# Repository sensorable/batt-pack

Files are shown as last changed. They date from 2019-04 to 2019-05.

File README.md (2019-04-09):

# 2P3S Battery Pack
### Designed for use with Sensorable Open Source Cameras

## Specification

* Charging voltage: 14v ... 36v
* Output voltage: 9.3v ... 12.6v
* Batteries: Li-Ion 18650 x3 or x6
* Operational temp: 0C ... 40C
* Enclosure: RP1170
* Water ingress: IP65 with a breathable valve
* Size: 165mm x 86mm x 40mm

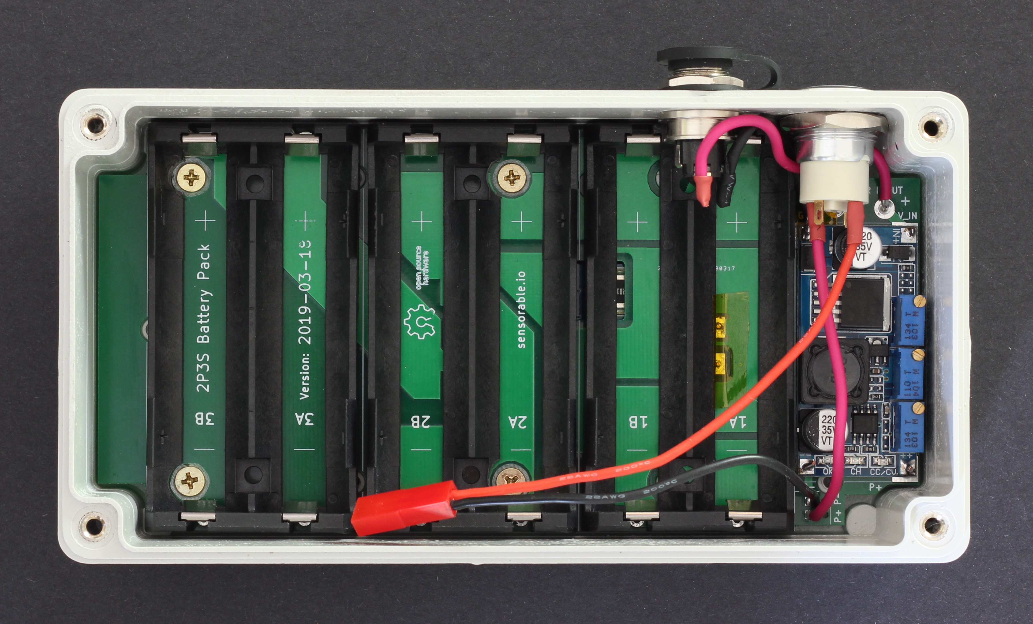
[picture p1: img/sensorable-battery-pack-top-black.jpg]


## Overview

This battery pack combines several COTS components to allow short production runs with manual assembly. All components are "though-hole" and the whole unit can be ordered and put together by any sufficiently skilled individual. It is not suitable for an automated PCBA process or large production runs.

Charging sources:

* a laptop charger with a barrel connector
* an intermittent power source like street lights, via a transformer
* a solar panel, but the efficiency can be low due to lack of MPPT

**Restarting the pack**

1. Insert the batteries
2. Connect a charger for a brief moment

The BMS requires external voltage close to the pack output to be connected from the outside for it to start working. You need to connect a charger or any similar source of voltage if you removed and re-inserted the batteries.

## Batteries

**Use only high quality Li-Ion 18650 batteries from a trusted manufacturer, e.g. NCR18650B and NCR18650GA from Panasonic.**

The battery holders are connected as 2P-3S, that is, the 2 batteries in the same holder are connected in parallel and the holders are connected in series. This way you can use either 3 or 6 battery cells.

* 3-cell configuration: place one battery into each holder numbered 1,2,3
* 6-cell configuration: fill in all available slots

The charger unit has to be adjusted to the battery type and the size of the pack. Use the 2 blue potentiometers to set the voltage to 4.2v and limit the current to less than 1A, if using NCR18650GA. Check your battery datasheet if using a different type.

The batteries are protected with a commercial BMS module with load balancing. Use only new batteries from the same batch and at exactly the same voltage. The load balancing feature will maintain them in that state, but it will not balance out mismatched batteries.

**BMS spec from the manufacturer datasheet:**
* Charging voltage: 12.6v
* Balance voltage per cell: 4.2v
* Balance current per cell: 42mA
* Max discharge current: 4.5A
* Overcharge protection: 4.35v +/-0.025v
* Overdischarge protection: 2.7v per cell

## Ordering and assembly

1. See the BOM file for the list of components and suppliers
2. We used JLCPCB for making the PCBs with a good result
3. Use cutting and drilling templates from the repo to modify the enclosure

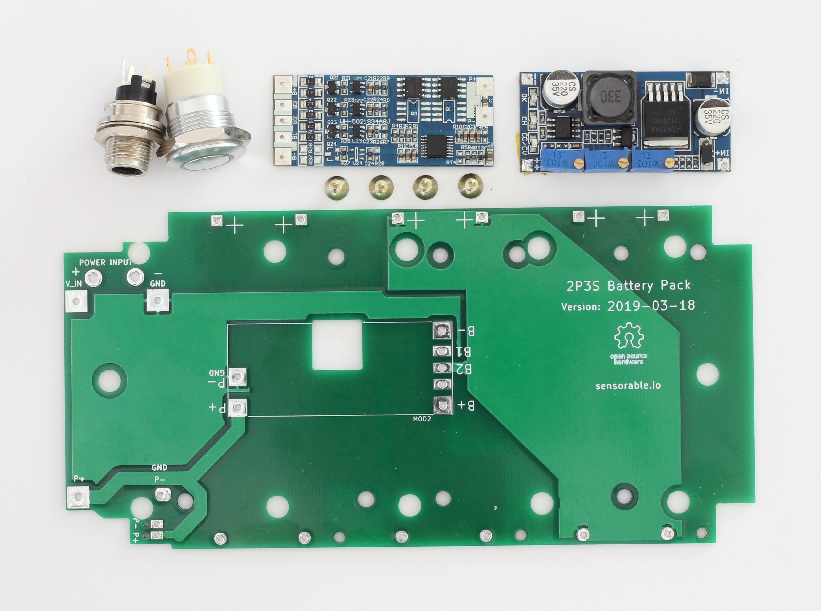
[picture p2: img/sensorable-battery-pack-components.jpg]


## Enclosure assembly instructions

* Trim the breathable valve by 4mm if placed on the back face under the board. Insert the valve from the inside of the case, tighten the nut back side out, cut off the white plastic flush to the nut.
* Counter-sink post to match the board counter-sinks 
* Mark holes for the switch and PWR IN.
* Check that the holes are marked correctly in relation to the countersunk holes and the vent.

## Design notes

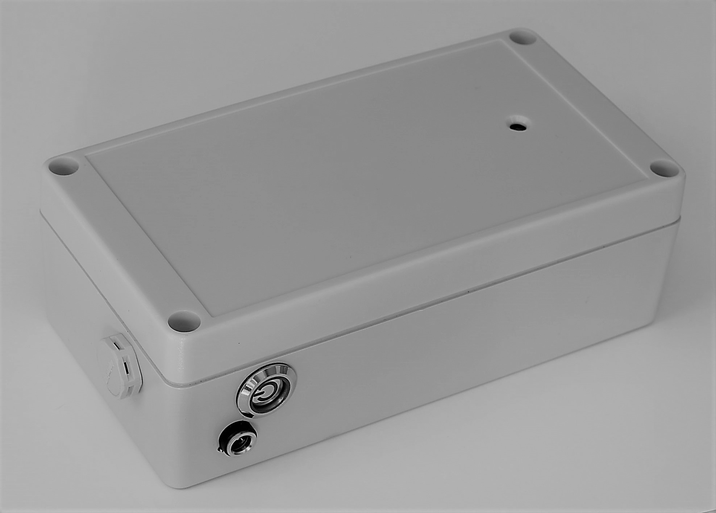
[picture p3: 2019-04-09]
img/full-enclosure-with-batt-pack.jpg

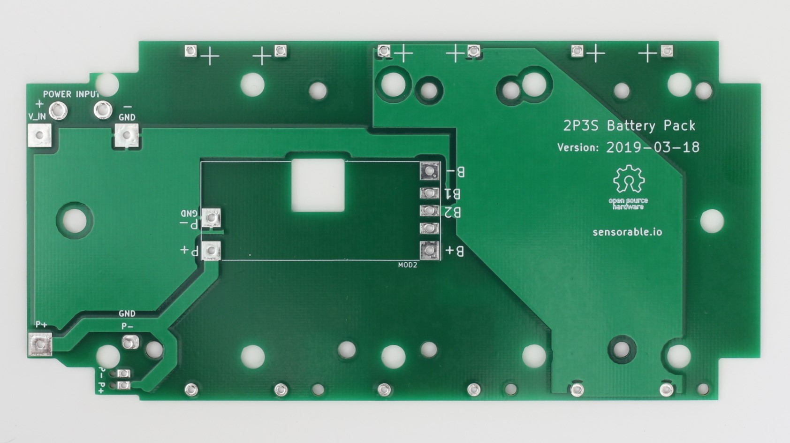
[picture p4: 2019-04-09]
img/batt-pack-pcb.jpg

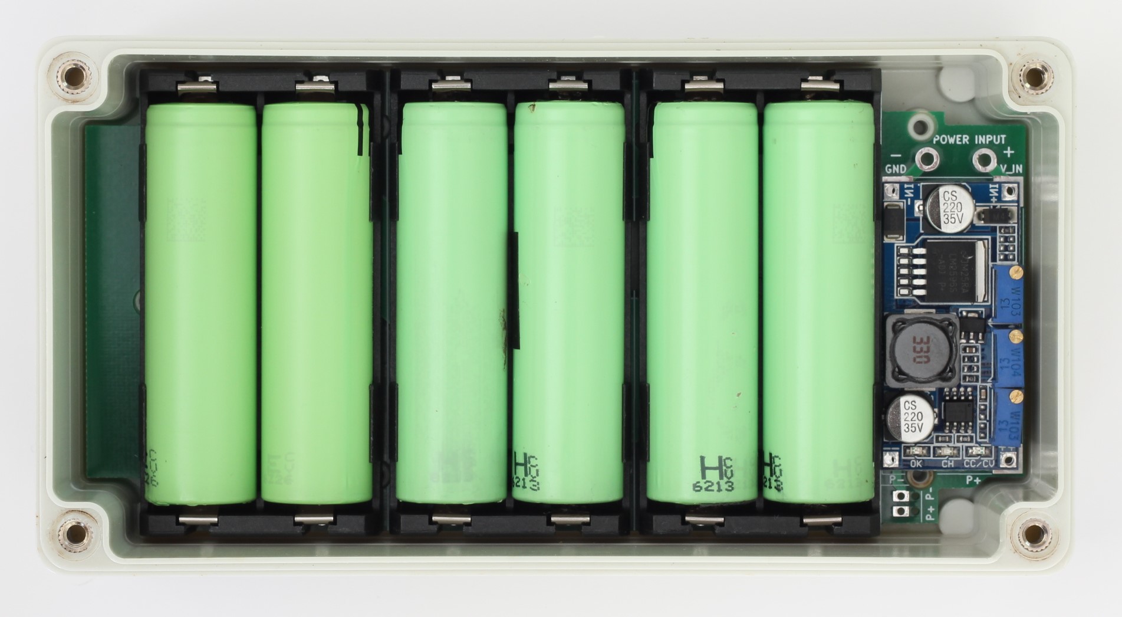
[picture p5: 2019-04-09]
img/batt-pack-w-batt2.jpg

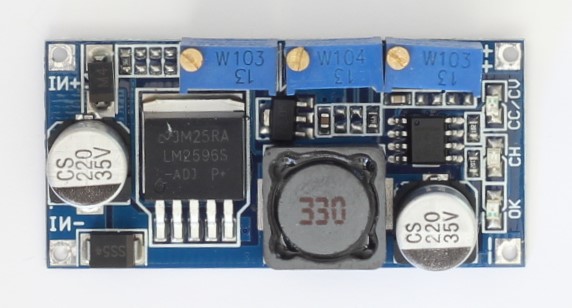
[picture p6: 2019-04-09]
img/cc-cv-3pots.jpg

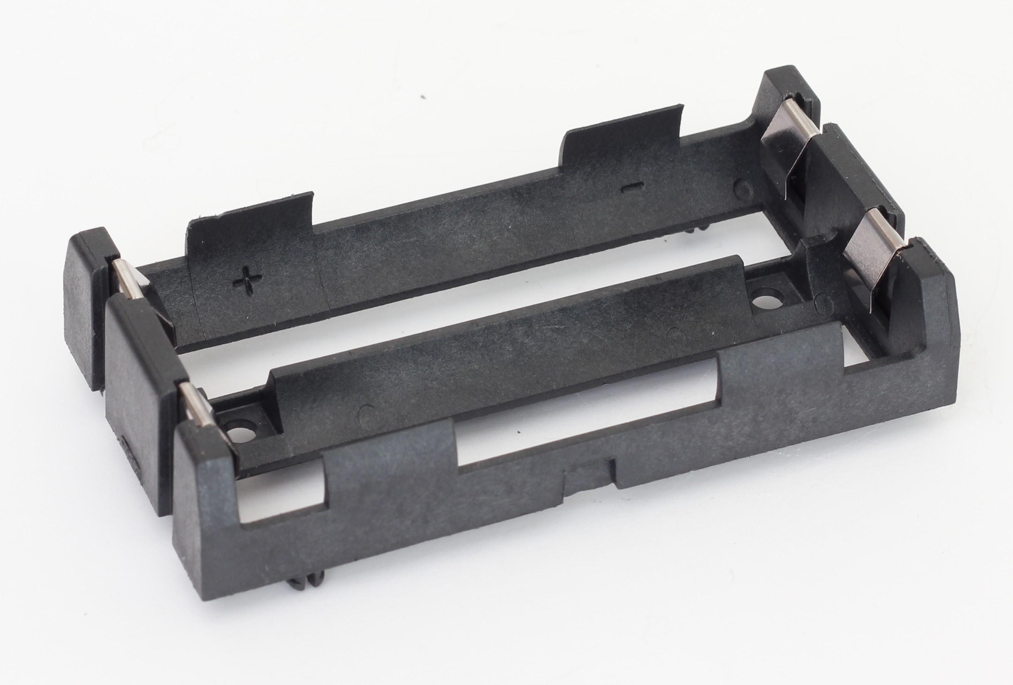
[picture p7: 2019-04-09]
img/keystone-18650-holder-1049-side-top.jpg

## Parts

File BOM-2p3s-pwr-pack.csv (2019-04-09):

Component | Supplier SKU | Manufacturer SKU | Qty per unit | Supplier link | Comments
PCB |  |  | 1 | https://jlcpcb.com/
BMS w/load balancing |  |  | 1 | https://www.aliexpress.com/item/3S-4A-11-1V-li-ion-BMS-PCM-battery-protection-board-bms-pcm-with-balancing-for/32377617462.html | Verify the pads match
CC/CV DC/DC converter |  |  | 1 | https://www.aliexpress.com/item/DC-DC-LM2596-HV-S-60V-3A-Buck-Constant-Current-Voltage-CC-CV-Step-Down-Module/32756197860.html | Must be exactly the same model to fit other components around it.
Thermal pad | 1168-2175-ND | TGX-150-150-1.5 | 0.02 | https://www.digikey.com/product-detail/en/t-global-technology/TGX-150-150-1.5/1168-2175-ND/7360875 | The sheet cuts into 50 pcs of 15mmx30mm. Place under CC/CV
IP65 latching button switch | EG5508-ND | PVA6LRE21231 | 1 | https://www.digikey.com/product-detail/en/PVA6LRE21231/EG5508-ND/7423421/?itemSeq=287488044 | Power On/Off
Barrel jack, 2.5/5.5 | SC1393-ND | PCL722AS | 1 | https://www.digikey.com/product-detail/en/PCL722AS/SC1393-ND/2238436/?itemSeq=287374077 | External charger connector
Rubber seal | SC1396-ND | JCAP | 1 | https://www.digikey.com/product-detail/en/switchcraft-inc/JCAP/SC1396-ND/2251492 | For the barrel jack
Battery holders for 18650 | 36-1049-ND | 1049 | 3 | https://www.digikey.com/product-detail/en/keystone-electronics/1049/36-1049-ND/2745670
JST RCY pre-crimped leads |  |  | 1 | https://www.trademe.co.nz/electronics-photography/other-electronics/electronic-components/other/listing-1980231570.htm | No major distributors stock pre-crimped ones. Source from a local hobby store.
4G x 8 plastite screws | SPK45-3-8-A2 | SPK45-3-8-A2 | 5 | https://www.accu.co.uk/en/plastite-45-pozi-countersunk-screws/24197-SPK45-3-8-A2 | These are supplied with the enclosure, but we may need CSK
Jumper wire |  |  | 1 |  | Soldering the pushbutton, jack, etc.
NCR18650xx batteries |  |  | 6 |  | Adjust the current on CC/CV to match the battery capacity

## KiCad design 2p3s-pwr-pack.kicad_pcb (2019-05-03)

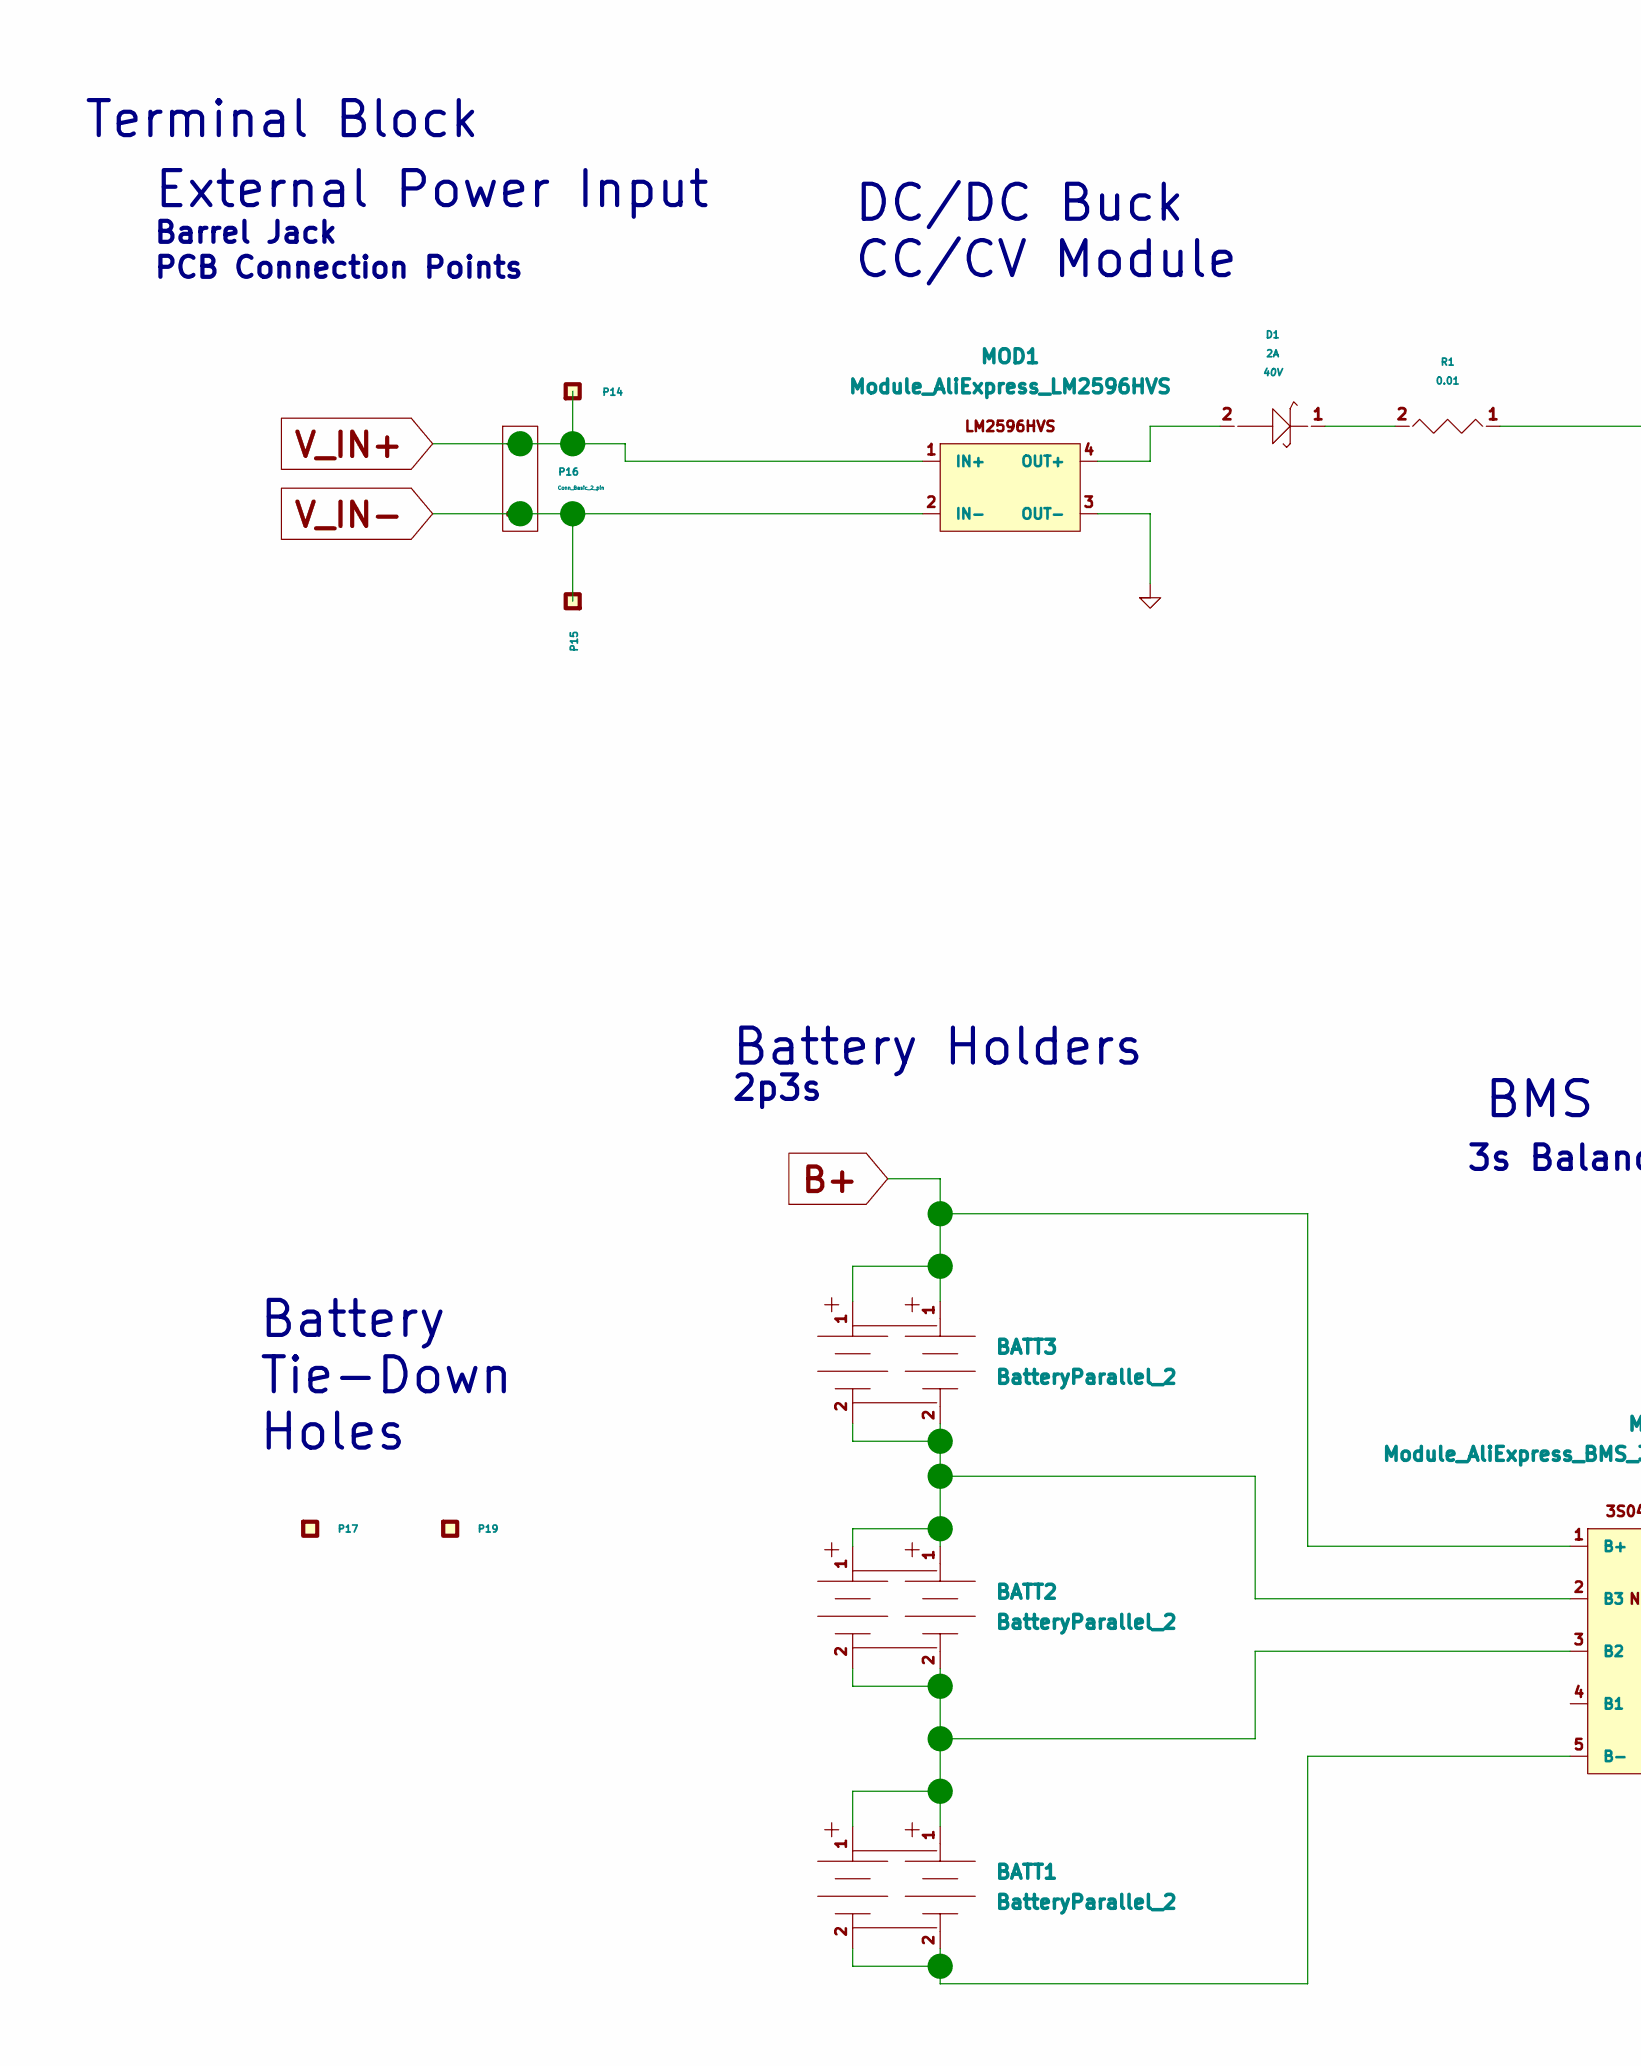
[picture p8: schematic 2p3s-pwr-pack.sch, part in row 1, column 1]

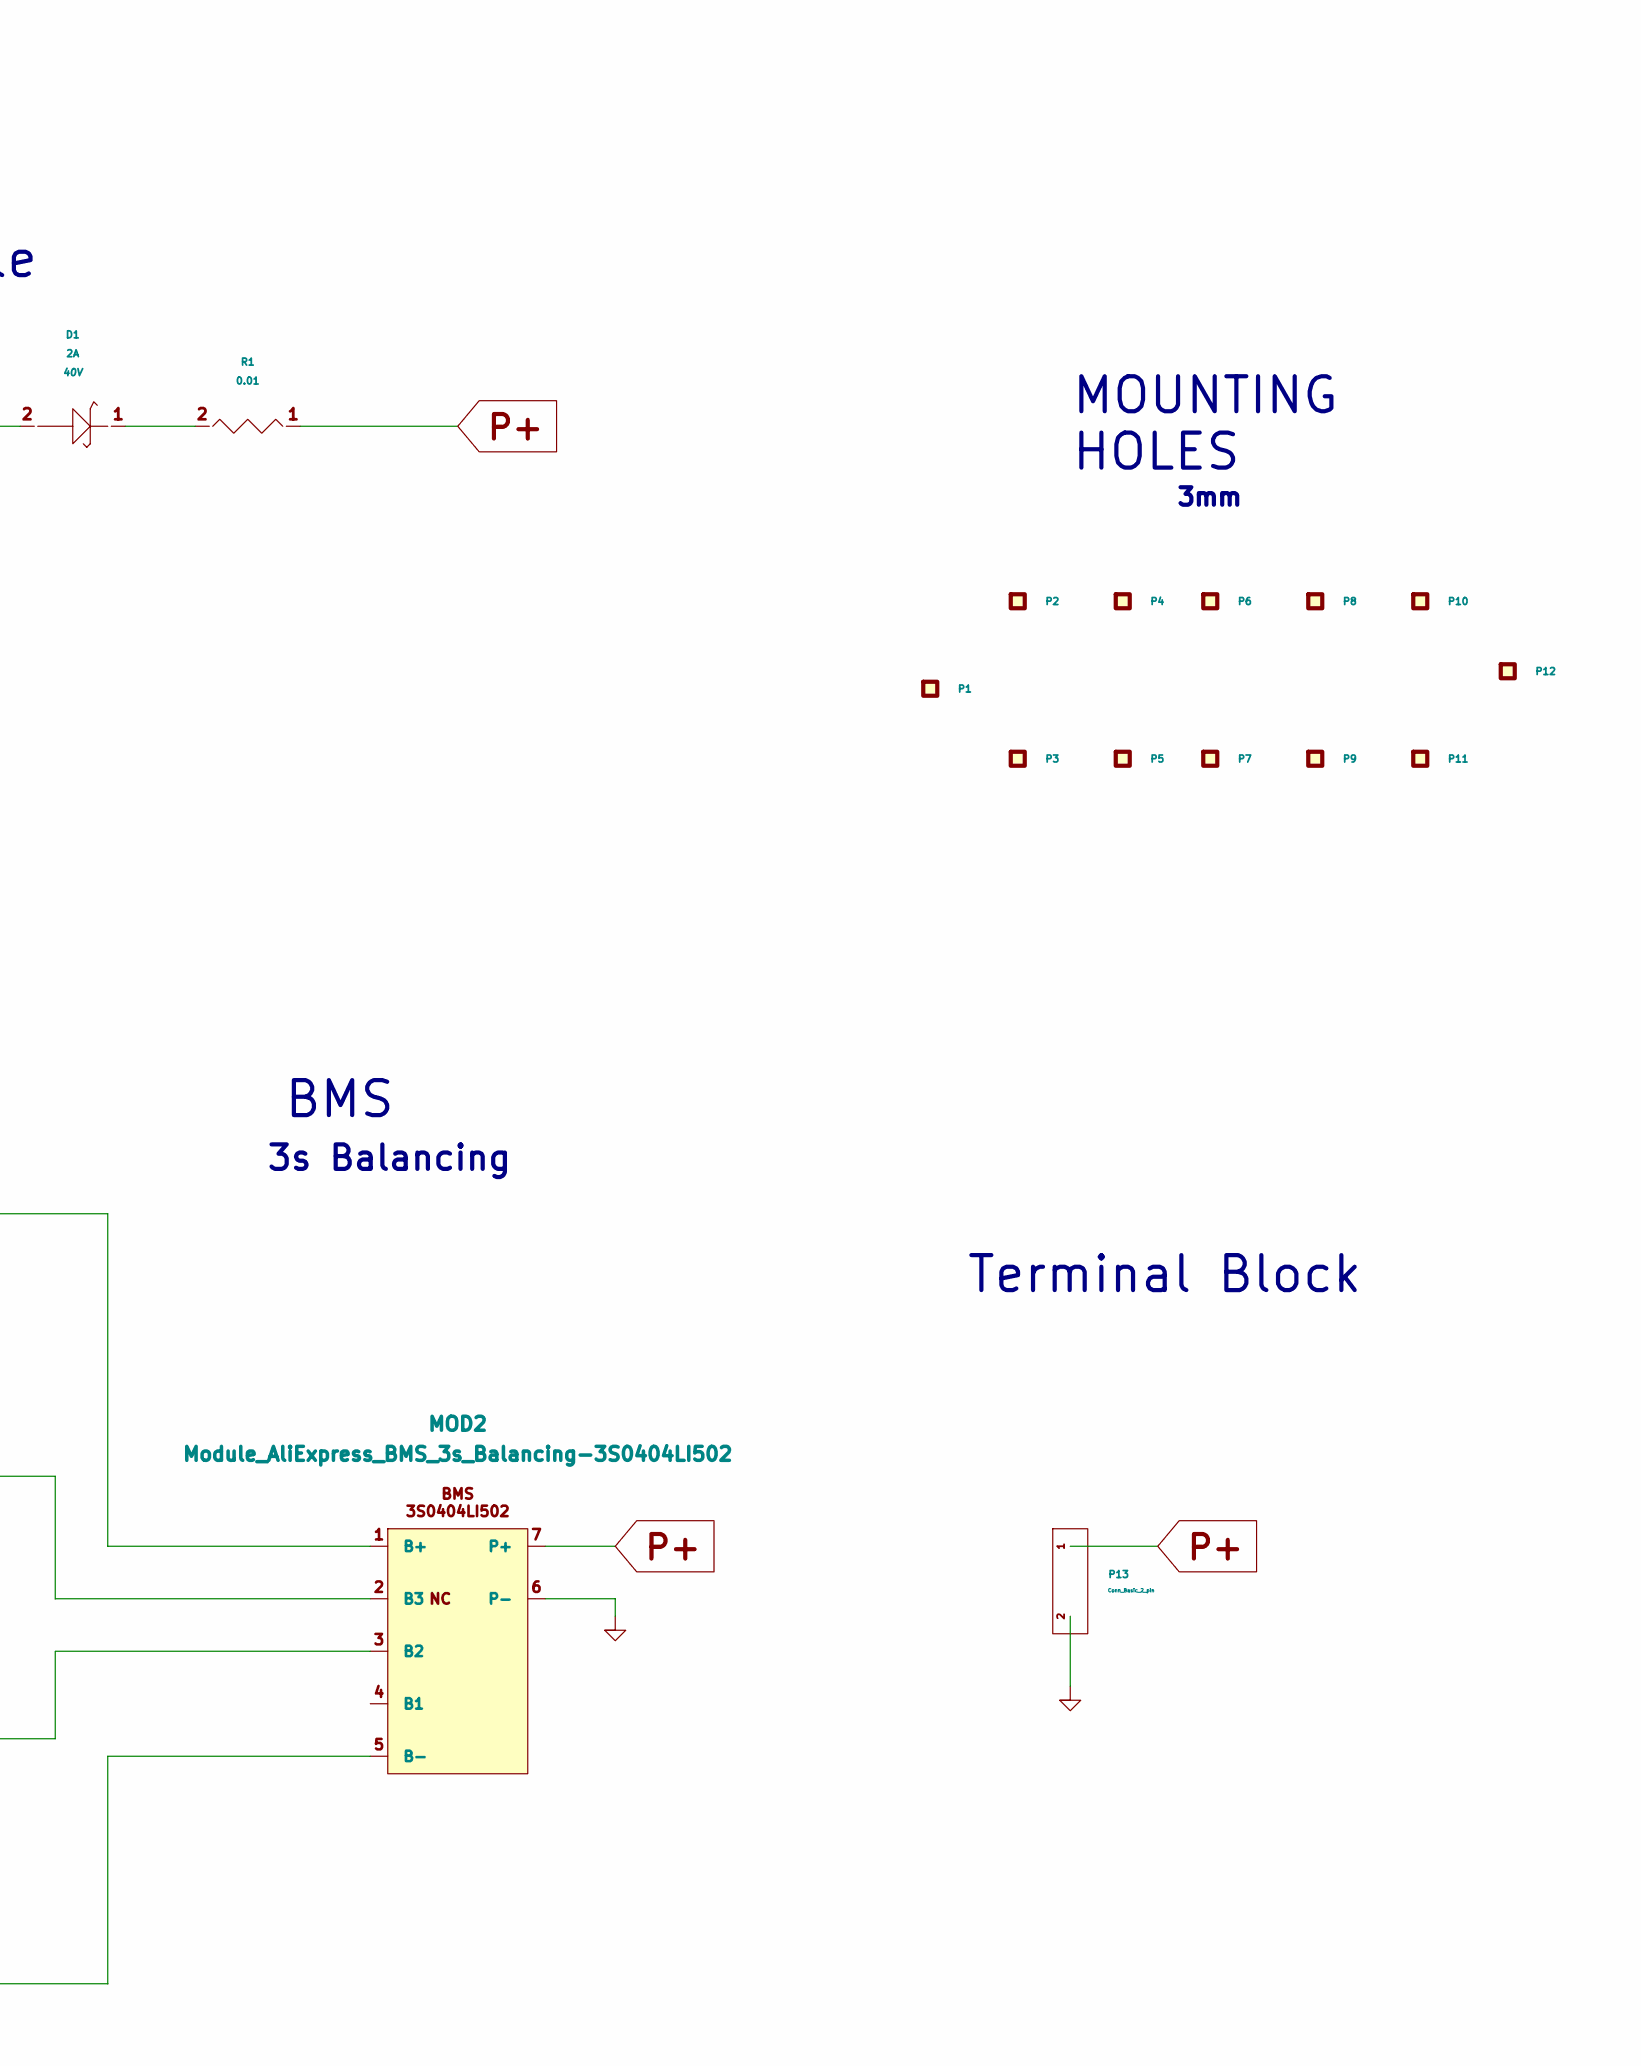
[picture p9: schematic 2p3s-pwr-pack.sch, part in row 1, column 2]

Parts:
BATT1, BATT2, BATT3: BatteryParallel_2; KEYSONE_1049_2x_18650_HOLDER; Manufacturer1PartNumber 1049
D1: 2A; SMA; Voltage 40V; Manufacturer1PartNumber B240AE-13
MOD1: Module_AliExpress_LM2596HVS
MOD2: Module_AliExpress_BMS_3s_Balancing-3S0404LI502; Module_BMS_Balancing_3s_AliExpress_BMS-3S0404LI502; Manufacturer1PartNumber MFG1PN
P1, P2, P3, P4, P5, P6, P7, P8, P9, P10, P11, P12: PAD; NPTH_5mm; Manufacturer1PartNumber MFG1PN
P13, P16: Conn_Basic_2_pin; TERM_BLK_2_SIDE_2.54MM; Manufacturer1PartNumber 1725656
P14, P15: PAD; HOLE_4mmx2.2mm; Manufacturer1PartNumber MFG1PN
P17, P19: PAD; NPTH_3mm; Manufacturer1PartNumber MFG1PN
R1: 0.01; 1206_Medium_Pads; Tolerance 5%; Manufacturer1PartNumber ERJ-8CWJR010V

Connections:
B+: BATT3.1, MOD2.1 (B+)
GND1: MOD1.3 (OUT-), MOD2.6 (P-), P13.2
unnamed: BATT1.1, BATT2.2, MOD2.3 (B2)
unnamed: BATT1.2, MOD2.5 (B-)
unnamed: BATT2.1, BATT3.2, MOD2.2 (B3)
unnamed: D1.1, R1.2
unnamed: D1.2, MOD1.4 (OUT+)
P+: MOD2.7 (P+), P13.1, R1.1
V_IN+: MOD1.1 (IN+), P14.1, P16.1
V_IN-: MOD1.2 (IN-), P15.1, P16.2

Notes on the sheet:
MOUNTING HOLES
3mm
Terminal Block
External Power Input
Barrel Jack
PCB Connection Points
Battery Holders
3s Balancing
BMS
2p3s
DC/DC Buck CC/CV Module
Battery Tie-Down Holes

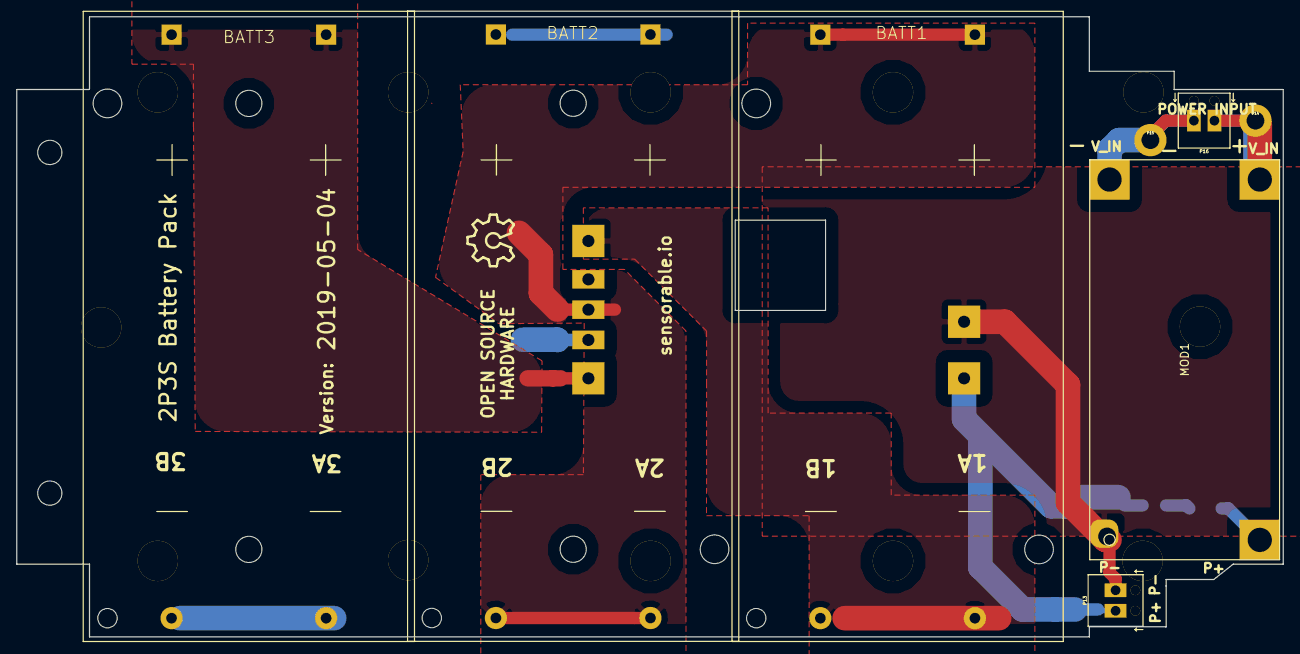
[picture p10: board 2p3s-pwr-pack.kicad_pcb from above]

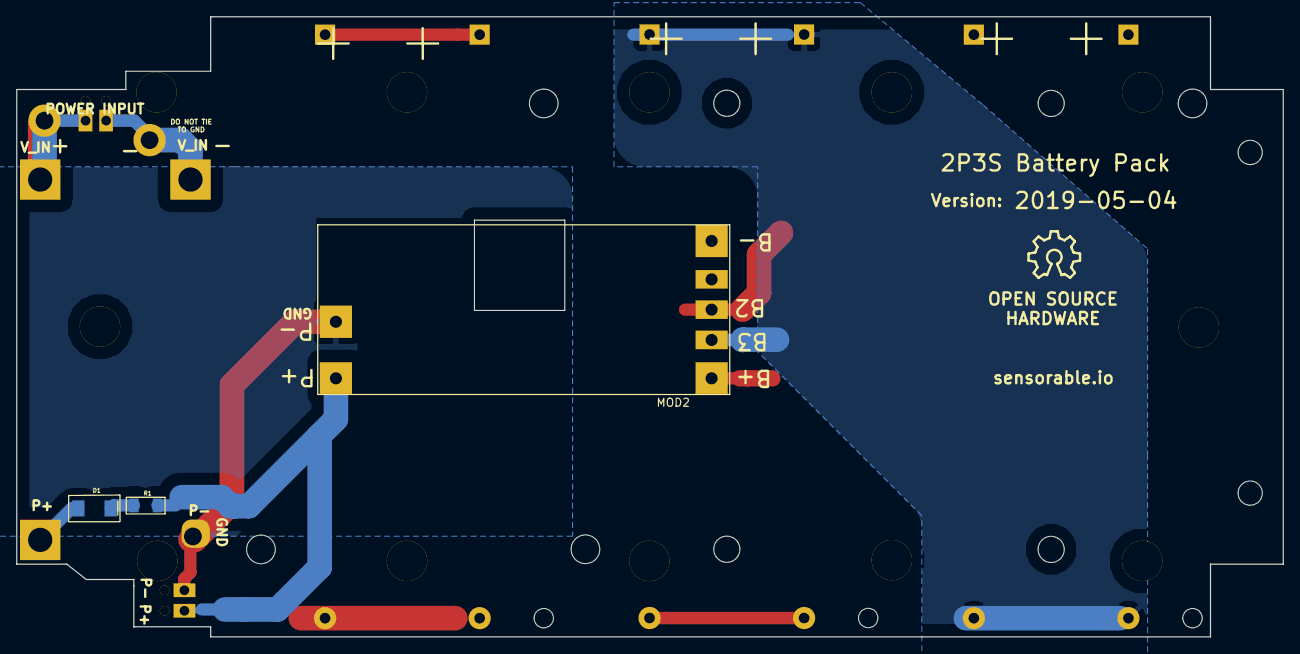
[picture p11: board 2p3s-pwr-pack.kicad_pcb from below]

Board: 2 copper layers, 156.8 x 76.8 mm, 25 parts (3 on the bottom side), 10 nets.

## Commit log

2019-03-16 A prorotype for review
    [2p3s-pwr-pack.kicad_pcb, 2p3s-pwr-pack.sch]
2019-03-16 Git LFS fix - added .stl
2019-03-17 2019-03018 ready for ordering.
    [2p3s-pwr-pack-B.Cu.gbl, 2p3s-pwr-pack-B.Fab.gbr, 2p3s-pwr-pack-B.Mask.gbs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]
2019-03-17 Added BOM
    [2p3s-pwr-pack-bom.csv]
2019-03-24 BOM and Readme updates.
    [2p3s-pwr-pack-bom.csv]
2019-04-09 Missin KiCad files.
2019-04-09 Renamed BOM
    [BOM-2p3s-pwr-pack.csv]
2019-04-16 Schematic, PCB changes
    Move holder 3 1mm West, holder 2 2mm west, holder 1 3mm west.
    SMA schottky diode on output of CC/CV.
    Fix B1/B3 mixup on BMS
    CC/CV input (-) no longer tied to GND (defeats CC mode)
    [2p3s-pwr-pack.sch]
2019-04-24 Finish JIRA EL-169 changes
    move battery holders, change some holes, add current sensing diode, updates to logo, VIN terminal block
    [2p3s-pwr-pack.kicad_pcb, _saved_2p3s-pwr-pack.sch]
2019-04-30 remove hole in the way
    battery mounting clip in the middle interfered with enclosure stantion boss. removed the battery mounting clip
    [2p3s-pwr-pack-B.Cu.gbl, 2p3s-pwr-pack-B.Fab.gbr, 2p3s-pwr-pack-B.Mask.gbs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]
2019-04-30 Create Sensorable2p3s_Ver30Apr2019_PCB_MFG_Gerbers.zip
    Gerber output for PCB manufacturing (no assembly process on this one).
    Simply upload to SeeedStudio, OSHPark, etc. or forward to PCB manufacturer.
2019-05-03 remove old gerber files
    remove folders containing old gerbers used for verification of the outputs
    [2p3s-pwr-pack-B.Cu.gbl, 2p3s-pwr-pack-B.Fab.gbr, 2p3s-pwr-pack-B.SilkS.gbo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]
2019-05-03 PCB ready for manufacture, added mfg files
    Gerber folder containing PDF printouts and gerber outputs of the PCB production data.
    The .zip can be uploaded directly to Seeed/Oshpark/etc. or sent to a PCB manufacturer for PCB manufacturing.
    [2p3s-pwr-pack-B.Cu.gbl, 2p3s-pwr-pack-B.Fab.gbr, 2p3s-pwr-pack-B.Mask.gbs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]
2019-05-03 delete old test gerbers
    delete
    [2p3s-pwr-pack-B.Mask.gbs]
2019-05-03 KiCAD design files as in 3May2019 gerber files
    These are the KICAD design files that the may3 gerber outputs were produced from.
    [2p3s-pwr-pack.kicad_pcb, 2p3s-pwr-pack.sch, _saved_2p3s-pwr-pack.sch]
2019-05-16 Rename output folder. Track .zip with LFS.
    [2p3s-pwr-pack-B.Cu.gbl, 2p3s-pwr-pack-B.Fab.gbr, 2p3s-pwr-pack-B.Mask.gbs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]
